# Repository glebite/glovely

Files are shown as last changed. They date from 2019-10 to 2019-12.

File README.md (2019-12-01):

# glovely
A presentation tool with a laser!

# Overview:
Essentially this is Yet Another Glove Build (YAGB) which will allow the user to point their index finger and it will shoot out a laser pointer.  Closing the hand will turn it all off.  Two buttons will be on the index finger: page forward, page back.  Giving a thumbs up will make a happy face on the glove/circuit enclosure.  Expecting to use flex sensors, an HID capable dev board that can handle the flex sensors and happy face output.  Bluetooth yeah.  

# inspired by:  
[Instructables Flex Sensor Glove](https://www.instructables.com/id/Flex-Sensor-Glove/)  
[Instructables Arduino Flex Sensor Glove](https://www.instructables.com/id/Arduino-Flex-Sensor-Glove/)

# materials arriving
2 sheets of velostat!

# materials arrived!  
Yes!

# located wearable material
wearable materials

# built my first ever flex sensor with Gorilla tape, conductive thread, and velostat!
first sensor

# index finger - 60 mm x 10 mm
# thumb - 70 mm x 10 mm

# 3D printed sensor mounts
Essentially I'm hoping to use snaps to connect the flex sensor to the glove
but the female connector (top) would be bumpy and warping the sensor.  I
designed and 3D printed parts to fit the female top snap.  The sensor can
then be glued to the top of the snaptops.

snap tops

# button work
Hardware is starting to come together.
Ordered the dev board.
Started to assemble the button board.

button board

# case and components added  
3d printed the case and the tolerances are too tight!!!  
again, I'm learning that I need to design my own parts and not trust ones that I find online  
case and parts  

# dremel time tonight
  4.921 mm (width of battery)  
- 4.723 mm (width of case)  
----------  
  0.198 mm  

  2.299 mm (width of feather)
- 2.241 mm (width of case)
----------
  0.058 mm
  
I'll clamp the unit into my vise and be very very careful...  :)  
(also use safety goggles!)  

# Dremel work is coming along okay - CPU board fits (also soldered headers)
Yup - working thus far - need to do some more surgery.

better fit

# fitting fine
Ugly dremel hacks but the battery fits too now!  
itfits  

# now on glove
Yes!  Yes!  Awesomeness!!!  This works!
glove

# power rail board soldered
Yup!  Getting closer!  
glove and stuff

# laser mounted to holder and on the glove
It is now on - fits well and points nicely  
glove and laser

# new sensor design - tired.
I will have more progress tomorrow after I get a good day!  
new sensor design

# using old sensor  
I got the old sensor working, wired, and tested.  Built a new sensor interface board - mounted sensor mounts on the glove.  
new board

# flex sensor and laser together - mostly working...
Yup - mostly working but coming along - now onto the buttons...  
laser mounted, etc...

# performed presentation without glovely... :(
It is true - sad but true.  The presentation went well but could have been cooler with the glove.

# new button board
Yup - back at it - soldered new button board and tested continuity
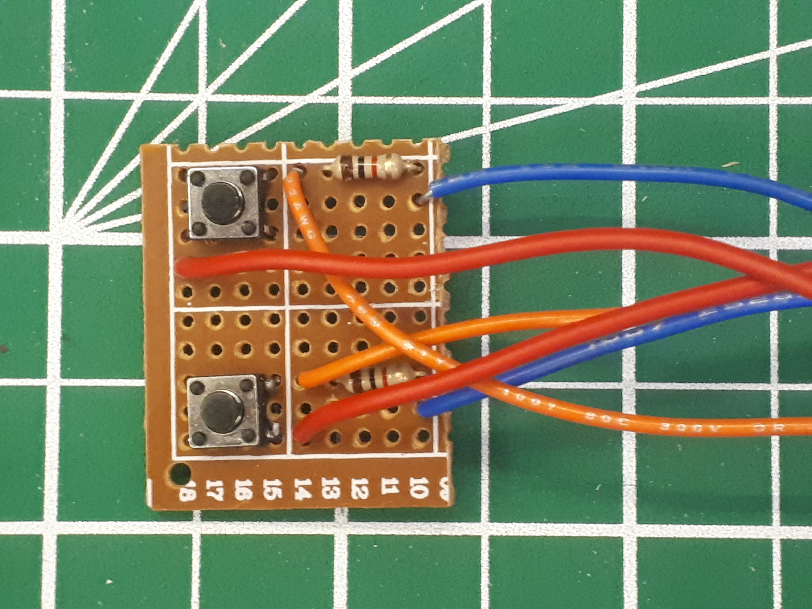
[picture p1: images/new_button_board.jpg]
button board


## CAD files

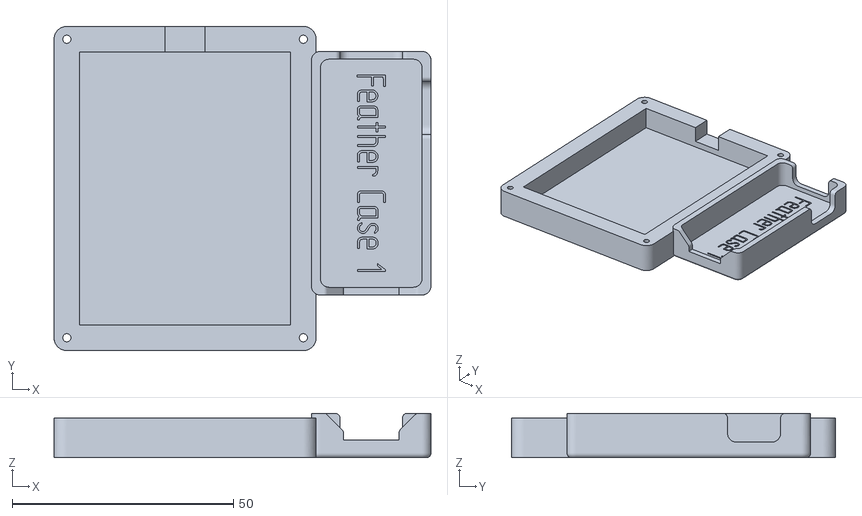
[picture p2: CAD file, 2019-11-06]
images/feather-battery-mount.stl
85.1 x 73.2 x 10.0

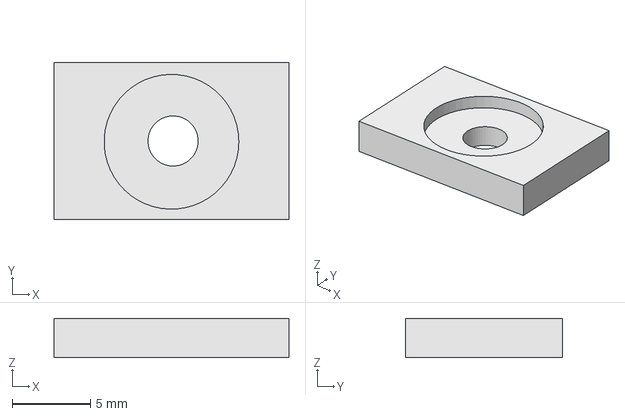
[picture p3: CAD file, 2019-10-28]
images/snaptop.FCStd
15.0 x 10.0 x 2.50 mm

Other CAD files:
images/snaptop.stl

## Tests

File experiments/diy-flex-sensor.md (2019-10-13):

Following instructions from:  
  
[instructables](https://www.instructables.com/id/DIY-Flex-Sensor-Under-1-/)  

# first try soldering to Aluminum:  
- failed - cold solder joint.  Not great quality.  
- received one bit of advise to warm/heat underneath (might work but afraid of carbon scoring on back preventing form adhesion to the paper strip...  
- received an idea to do more of a rat's tail attachment - might work too.

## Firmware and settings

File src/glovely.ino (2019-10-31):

/*
	glovely.ino

	A flex-sensor driven glove to allow for bluetooth controls over a
	presentation system and built-in laser pointer and extra fun!

	Flex sensor on index finger - when extended activates laser pointer
	Flex sensor on the thumb - activates the happy face
	Button on the index finger is forward page
	Button on the index finger is backward page
	
	The circuit:
	-
	-
	-

	Copied 2019-10-04
	https://www.instructables.com/id/Arduino-Flex-Sensor-Glove/
	Modified 2019-10-04
	Me.

	https://github.com/glebite/glovely
*/


#define FLEXINDEX A2 
#define FLEXTHUMB A3
#define FLEXSENSORPIN0 0
#define BUTTON_FORWARD D0
#define BUTTON_BACKWARD D1

float singleReading(int);

//defined variables for each sensor according to finger
float indexReading;
float thumbReading;

int ledAnalogOne[] = {5,6};

void setup(void) {
  Serial.begin(9600);
	Serial.println("Configuring up output pins");
  for(int thisPin = 0; thisPin < 2; thisPin++){
   pinMode(ledAnalogOne[thisPin], OUTPUT);   //Set the three LED pins as outputs
  }
}
 
void loop(void) {
  indexReading = singleReading(FLEXINDEX);
  thumbReading = singleReading(FLEXTHUMB);
  
  Serial.print("Single reading Index "); 
  Serial.println(indexReading);

  Serial.print("Single reading Thumb "); 
  Serial.println(thumbReading);

	if (indexReading > LASER_ON) {
		// call laser_on function
	} else {
		// call laser_off function
	}

	if (thumbReading > THUMBS_UP) {
		// happy face on
	} else {
		// happy face off
	}
  delay(1000);
}

/**
 * gets a reading from an analog pin
 * @param pin the pin to read from
 * @return the reading
 */
float singleReading(int pin)
{
  float reading;
  reading = analogRead(pin);
  return reading;
}

/**
 * maps an analog reading to a value between 0-254, 254 used for demonstration purposes to show that values were 
 * being read and manipulated at all times. bottom and top values used are the average values when the sensor is bent (bottom)
 * and when it is held straight (top)
 * @param analogReading reading to be mapped
 * @param bottom the value used as the minimum value for the sensor
 * @param top the value used as the maximum value for the sensor
 * @return mapped value to be used for the RGB light
 */
float mapReading(float analogReading, float bottom, float top)
{
  float calibratedValue;
  if(analogReading > top)
  {
    calibratedValue = 254;
  }
  else if(analogReading < bottom)
  {
    calibratedValue = 0;
  }
  else
  {
    calibratedValue = map(analogReading, bottom,top,0,254); 
  }
  return calibratedValue;
}

/**
 * gets and print the average values taken from the sensor as per the NUMSAMPLES variable
 */
void average()
{
  int NUMSAMPLES = 100;
  uint8_t i;
  float average;
  int samples[NUMSAMPLES];
  
    // take N samples in a row, with a slight delay
  for (i=0; i< NUMSAMPLES; i++) {
    //Change the pin according to which sensor you are calibrating
   samples[i] = analogRead(FLEXSENSORPIN0);
   delay(10);
  }

  // average all the samples out
  average = 0;
  for (i=0; i< NUMSAMPLES; i++) {
     average += samples[i];
  }
  average /= NUMSAMPLES;
 
  Serial.print("Average reading "); 
  Serial.println(average);
}

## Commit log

2019-10-06 start of diy-flex-sensor experiment.
2019-10-08 updated materials section'
2019-10-13 added picture of wearable gear
2019-10-24 push glovely.hex to the arduino
2019-10-27 Updated measurements, image of measurements of materials, some code?
2019-10-27 adding in button test picture - buttons work - need to put them on small circuit board and provide leads...
2019-10-28 Creating a snaptop - top piece of snap glues in here to provide a platform to attach the flex sensor.
    [snaptop.FCStd]
2019-10-29 Converted to stl - looks good in meshlab
    [snaptop.stl]
2019-10-30 3d printed parts are fitting - added in ring.
2019-10-30 Added in notes on the 3d printed sensor mounts
2019-10-31 index reading check as well as thumb - need to write laser and happy_face functions
2019-11-06 3d merged meshes - should print... (fingers crossed)
    [feather-battery-mount.stl]
2019-11-07 Added in picures of the case and components
2019-11-13 Laser mounted on glove
2019-11-18 updates and such - new sensor coming down the pipe...
2019-11-20 getting there - next is the buttons...
2019-12-01 New button board
